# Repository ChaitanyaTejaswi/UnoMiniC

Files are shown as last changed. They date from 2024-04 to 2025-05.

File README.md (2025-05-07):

# UnoMiniC

UnoMiniC is a compact, USB-C–powered Arduino Uno-compatible board designed for modern embedded development. It features the ATmega328PB and ATmega16U2 for reliable USB-to-serial communication with auto-reset support.

Created to address the size and USB limitations of traditional Arduino boards, UnoMiniC offers a Pico-sized design with breakouts for VIN, ICSP, and DTR reset. The board is powered and programmed through a USB C interface; a VIN pin breakout is provided in case it has to be ran on a battery pack. ICSP headers (as test points) is provided for  both  ATmega16U2  and  ATmega328PB.  On-board  auto  reset  is  configured  to  reset  the microcontroller  to programming  mode  when programming with  the  USB interface.

## Software Reqiurement  

**KiCAD**: Platform used to design the schematic and PCB layout.  
**Atmel FLIP**: Used for updating the atmega16U2 with USB interface firmware.  
**Arduino IDE/VSC**: Programming and testing the final board.

## Board Setup

### Flash USB-to-serial firmware in DFU mode

The firmware for ATmega16U2 is located inside `ArduinoCore-avr/firmwares/atmegaxxu2/arduino-usbserial/`.
Use the `Arduino-COMBINED-dfu-usbserial-atmega16u2-Uno-Rev3.hex` hex file.

> [!IMPORTANT]  
> Make sure that the fuses are set to utilise the external 16 MHz crystal oscillator and disable ```Divide clock by 8 internally``` by setting the ```CLKDIV8 bit``` in the CLKPR – Clock Prescale Register.

### Program the ATmega16U2 chip with USB-Serial firmware

#### Using dfu-programmer (macOS/Linux)

* Download **dfu-programmer** from the [GitHub repository](https://github.com/dfu-programmer/dfu-programmer/releases) or install the dfu-programmer package using a package manager like [homebrew](https://brew.sh/index) (macOS) or [apt-get](https://manpages.ubuntu.com/manpages/kinetic/en/man8/apt-get.8.html) (Ubuntu).

* Connect the board to your computer.

* Set the ATmega16U2 to DFU mode.
   - Short the RST Test Pad to the nearest available GND pin

* Open Terminal.

* Erase the memory.
   ```
   dfu-programmer atmega16u2 erase
   ```
* Flash the firmware.
   ```
   dfu-programmer atmega16u2 ./ArduinoCore-avr/firmwares/atmegaxxu2/arduino-usbserial/Arduino-COMBINED-dfu-usbserial-atmega16u2-Uno-Rev3.hex
   ```
* Disconnect and reconnect the board to your computer.

#### Using FLIP (Windows)

* Download and install [Flip](https://www.microchip.com/en-us/development-tool/flip).

* Connect the board to your computer.

* Set the ATmega16U2 to DFU mode.
   - Short the RST Test Pad to the nearest available GND pin

* Open FLIP.

* Connect to the chip by clicking the cable button, select USB, then click open.

* In the Menu, click Device > Select > ATmega16U2.

* Click File > Load HEX file

* Navigate to `ArduinoCore-avr/firmwares/atmegaxxu2/arduino-usbserial/`, select `Arduino-COMBINED-dfu-usbserial-atmega16u2-Uno-Rev3.hex` and then click OK.

* Click on the `Program Target Device Memory` button.

* The firmware will be flashed, and `Programming done` message should be displayed in the bottom-left corner.

### Download MiniCore 
#### Boards Manager Installation
This installation method requires Arduino IDE version 1.8.0 or greater.

* Open the Arduino IDE.

* Open the **File > Preferences** menu item.

* Enter the following URL in **Additional Boards Manager URLs**:

    ```
    https://mcudude.github.io/MiniCore/package_MCUdude_MiniCore_index.json
    ```

* Open the **Tools > Board > Boards Manager...** menu item.

* Wait for the platform indexes to finish downloading.

* Scroll down until you see the **MiniCore** entry and click on it.

* Click **Install**.

* After installation is complete close the **Boards Manager** window.

#### Manual Installation
Click on the "Download ZIP" button in the upper right corner. Extract the ZIP file, and move the extracted folder to the location "**~/Documents/Arduino/hardware**". Create the "hardware" folder if it doesn't exist.
Open Arduino IDE, and a new category in the boards menu called "MiniCore" will show up.

#### Arduino CLI Installation
Run the following command in a terminal:

```
arduino-cli core install MiniCore:avr --additional-urls https://mcudude.github.io/MiniCore/package_MCUdude_MiniCore_index.json
```

## Setting up the board for the first time

> [!NOTE]
> You will need an ICSP Programmer for this step as we need to flash the URBoot bootloader on the ATmega328PB.

* Under the boards menu: select **MiniCore > ATmega328**.

* Select Clock to **External 16MHZ** and Variant to **328PB**.

* Connect your ICSP programmer to the ICSP header on the back of the board.  

* Under **Tools**, select correct programmer and hit **Burn bootloader**.

The board is now setup and the USB C port can be used for serial programming just like any other microcontroller development board.

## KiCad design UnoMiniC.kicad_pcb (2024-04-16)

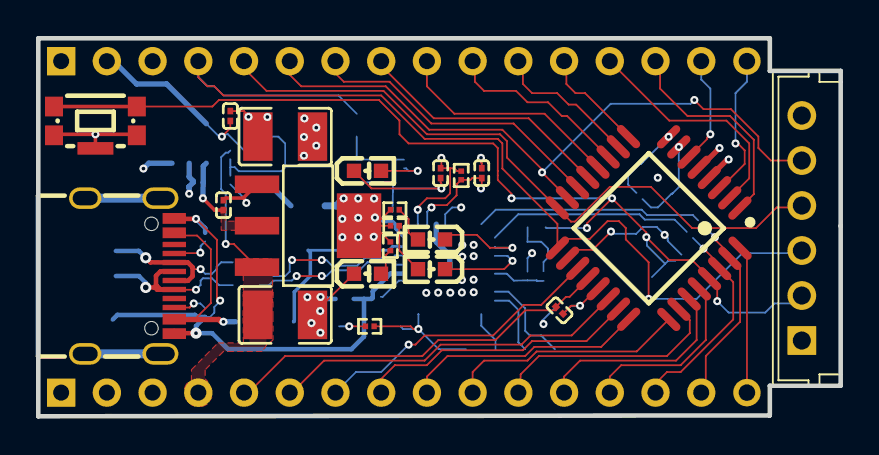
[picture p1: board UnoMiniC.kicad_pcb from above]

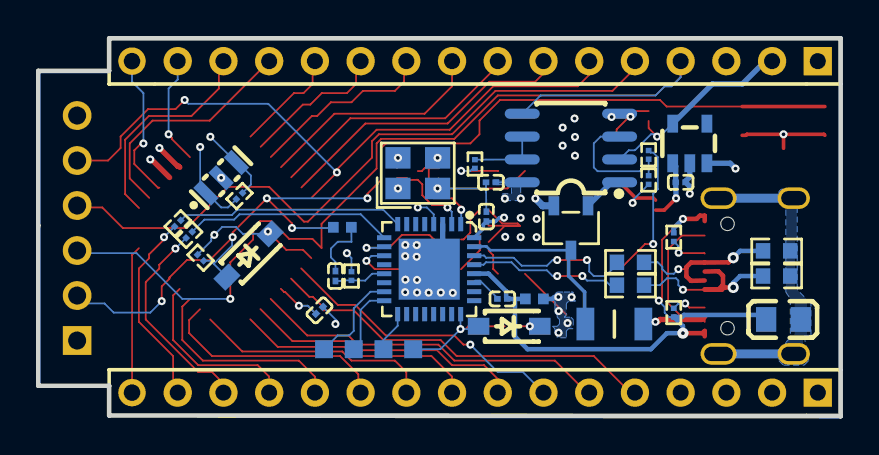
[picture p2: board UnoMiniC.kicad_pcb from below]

Board: 4 copper layers, 44.6 x 21.0 mm, 59 parts (34 on the bottom side), 62 nets.

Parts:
C1, C4, C11, C12, C13: 0.1u; C0201
C2, C3: 47uF; C1210
C5: 2.2u; C0201
C6, C9, C10: 1u; C0201
C7, C8: 10p; C0201
D1, D2: 1N4148WQ-13-F; SOD-123_L2.7-W1.6-LS3.7-RD-1
F1: PTS12066V050; FUSC3216X68N
J2: HDR-M-2.54_2x3; CONN-TH_6P-P2.50_JST_B6B-EH-LF-SN
J3, J4: HDR-M-2.54_1x16; HDR-M-2.54_1X16
L1: 220Ω; L0805
LED1, LED2, LED3, LED4: HSMQ-C191; LED-SMD_L1.6-W0.8-R-RD
Pad_gge82640: Pad_gge82640
Pad_gge82664: Pad_gge82664
Pad_gge82688: Pad_gge82688
Pad_gge82712: Pad_gge82712
Q1: DMG3415UQ-7; SOT-23-3_L2.9-W1.6-P1.90-LS2.8-BR
R1, R2, R13, R14: 510; R0201
R3, R4, R6, R17: 10k; R0201
R5, R16: 1M; R0201
R7, R8: 22R; R0603
R9, R12: 5.1k; R0201
R10, R11: CG0603MLC-05E; R0603
R15, R18: 0; RESC1005X37N
R19, R20, R21: 1k; R0201
SW1: KMR221GLFS; KEY-SMD_KMR2XXGXXX
U1: LM358DR; SOIC-8_L5.0-W4.0-P1.27-LS6.0-BL
U2: LD1117S33CTR; SOT-223-4_L6.5-W3.5-P2.30-LS7.0-BR
U3: LP2985IM5X-3.3; SOT-23-5_L2.9-W1.6-P0.95-LS2.8-BR
U4: ATMEGA16U2-MU; QFN-32_L5.0-W5.0-P0.50-BL-EP3.4
U5: ATMEGA328PB-AU; TQFP-32_L7.0-W7.0-P0.80-LS9.0-BL
USBC1: TYPE-C-31-M-12; USB-C_SMD-TYPE-C-31-M-12
X1: ABM8G-16.000MHZ-4Y-T3; CRYSTAL-SMD_4P-L3.2-W2.5-BL
X2: 16MHz; OSC-SMD_3P-L3.2-W1.3-P1.20-L

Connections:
3V3_LDO: C5.2, J4.2, U1.2, U3.5
5V_LDO: C1.1, C3.2, C4.2, C6.2, C9.2, C11.2, D1.1, D2.1, J2.1, J3.1, J4.1, Q1.2, R2.2, R6.2, R13.1, R14.1, R17.2, U1.8, U2.2, U2.4, U3.1, U3.3, U4.4, U4.32, U5.4, U5.18
ARD_AN0: J3.8, U5.23
ARD_AN1: J3.9, U5.24
ARD_AN2: J3.10, U5.25
ARD_AN3: J3.11, U5.26
ARD_AN4/SDA: J3.12, U5.27
ARD_AN5/SCL: J3.13, U5.28
ARD_DIG0: J3.14, R20.2, U5.30
ARD_DIG1: J3.15, R21.2, U5.31
ARD_DIG2: J3.16, U5.32
ARD_DIG3: J4.14, U5.1
ARD_DIG4: J4.13, U5.2
ARD_DIG5: J4.12, U5.9
ARD_DIG6: J4.11, U5.10
ARD_DIG7: J4.10, U5.11
ARD_DIG8: J4.9, U5.12
ARD_DIG9: J4.8, U5.13
ARD_DIG10/SPI_SS: J4.7, U5.14
ARD_DIG11/SPI_MOSI: J2.5, J4.6, U5.15
ARD_DIG12/SPI_MISO: J2.4, J4.5, U5.16
ARD_DIG13/SPI_SCK: J2.3, J4.4, U1.5, U5.17
ARD_RESET: D2.2, J2.2, R17.1, R18.2, SW1.3, SW1.4, U5.29
AREF: C12.2, J3.5, U5.20
DTR: C13.2, R19.2, U4.13
GND: C1.2, C2.1, C3.1, C4.1, C5.1, C6.1, C7.2, C8.2, C9.1, C11.1, C12.1, J2.6, J3.2, J3.3, J4.3, LED1.2, LED2.2, R4.1, R15.1, R19.1, SW1.1, SW1.2, SW1.5, U1.4, U2.1, U3.2, U4.3, U4.33, U5.5, U5.21, X1.2, X1.4, X2.2
ICSP_MISO: Pad_gge82688.3, U4.17
ICSP_MOSI: Pad_gge82664.2, U4.16
ICSP_SCK: Pad_gge82640.1, U4.15
LED2_1: LED2.1, R2.1
LED3_1: LED3.1, R13.2
LED4_1: LED4.1, R14.2
PE0: J4.16, U5.3
PE1: J4.15, U5.6
PE2: J3.7, U5.19
PE3: J3.6, U5.22
R1_2: LED1.1, R1.2
R18_1: C13.1, R18.1
SERIALRX: R20.1, U4.9
SERIALTX: R21.1, U4.8
SLD: L1.2, R10.1, R11.1, USBC1.0, USBC1.1, USBC1.2, USBC1.3
U1_1: Q1.1, U1.1
U1_3: R3.1, R4.2, U1.3
U1_7: R1.1, U1.6, U1.7
U4_1: C7.1, R5.2, U4.1, X1.3
U4_2: C8.1, R5.1, U4.2, X1.1
U4_10: LED3.2, U4.10
U4_11: LED4.2, U4.11
U4_24: D1.2, Pad_gge82712.4, R6.1, U4.24
U4_27: C10.1, U4.27
USBC1_A5: R12.2, USBC1.A5
USBC1_B5: R9.2, USBC1.B5
USBC1_B6: R8.1, R10.2, USBC1.A6, USBC1.B6
USBC1_B7: R7.1, R11.2, USBC1.A7, USBC1.B7
USBGND: C10.2, L1.1, R9.1, R12.1, R15.2, U4.28, USBC1.A1, USBC1.A12, USBC1.B1, USBC1.B12
USBV: F1.1, USBC1.A4, USBC1.A9, USBC1.B4, USBC1.B9
USBVCC: F1.2, Q1.3, U4.31
USB_D+: R8.2, U4.29
USB_D-: R7.2, U4.30
VIN: C2.2, J3.4, R3.2, U2.3
X2_1: R16.2, U5.7, X2.1
X2_3: R16.1, U5.8, X2.3
